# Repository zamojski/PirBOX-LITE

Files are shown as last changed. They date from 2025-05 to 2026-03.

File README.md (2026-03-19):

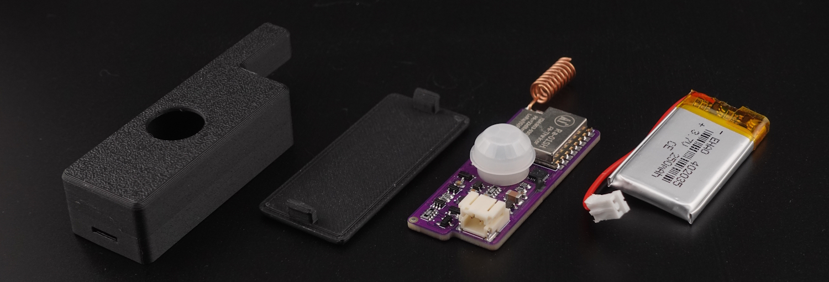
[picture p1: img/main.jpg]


🤗 Please consider subscribing to my [YouTube channel](https://www.youtube.com/@PricelessToolkit/videos)
Your subscription goes a long way in backing my work. If you feel more generous, you can buy me a coffee



## PirBOX-LITE and [PirBOX-MAX](https://github.com/PricelessToolkit/PirBOX-MAX)

**PirBOX-LITE** is an Open-Source, compact, low-power LoRa-based PIR motion sensor designed for long-range applications such as mailboxes, basements, underground "garages/parkings", and remote sheds. It is the improved, more affordable successor to the **[MailBox-Guard](https://github.com/PricelessToolkit/MailBoxGuard)** project.

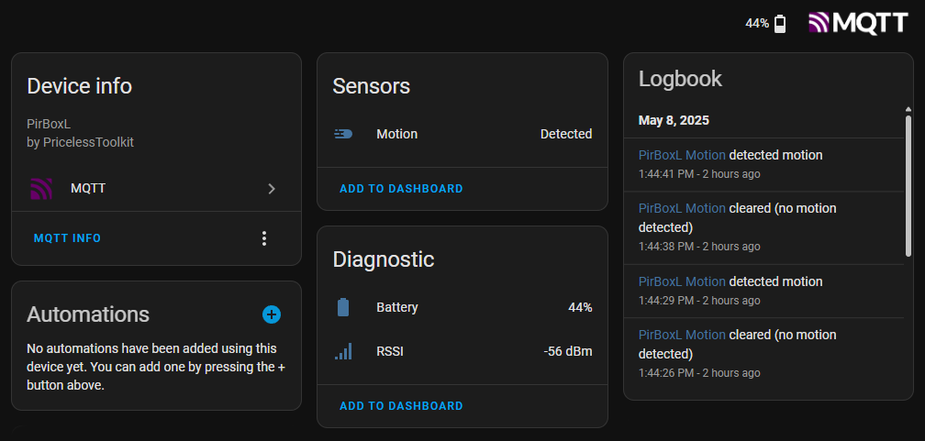
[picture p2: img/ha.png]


#### 🛒 Can be purchased in my shop http://www.PricelessToolkit.com

### ✨ Key Features:
- Seamless integration with **Home Assistant MQTT**  
- **LoRa-based communication** for long-range, low-power use cases  
- Sends **( Detected** / **Cleared )** statuses to a LoRa gateway "**[CapiBridge](https://github.com/PricelessToolkit/CapiBridge) or [LilyGo LoRa Board](https://github.com/PricelessToolkit/TTGO_Gateway)**"  
- **Ultra-low power consumption**: ~11 µAh when No motion detected
- Powered by a **250 mAh battery** for long-lasting operation
- Perfect for remote monitoring where Wi-Fi or Zigbee range isn't enough

> [!NOTE]
> **Not intended** for close proximity use or in high-traffic areas, Zigbee devices are better suited for those applications.

### 📋 Power Consumption Table
Measured by "Power Profiler KIT 2"

| Condition | Current Draw | Battery Life (approx.) |
|---|---|---|
| No motion detected | 11 µA | ~2.6 years (250 mAh / 11 µA) |
| Constant motion detected  | 25 µA | ~1.1 years (250 mAh / 25 µA) |
| Single status transmission (314 ms) | 4.02 µAh | ~62,188 sends (250,000 µAh / 4.02 µAh) |

> [!NOTE]
> Battery Life is only an approximate value. Actual battery life can vary depending on temperature, battery quality, configuration, and other factors.

### Required:
- [CapiBridge LoRa Gateway](https://github.com/PricelessToolkit/CapiBridge) has 2-Way communication and Encryption possibility, or the one-way more affordable version [TTGO_Gateway](https://github.com/PricelessToolkit/TTGO_Gateway) *no Encryption and future support is limited.
- Programmer [UNIProg](https://www.pricelesstoolkit.com/en/projects/33-uniprog-uartupdi-programmer-33v-0741049314412.html) or any other 3.3v UPDI Programmer
- LiPo Battery [1S 250mAh](https://www.pricelesstoolkit.com/en/products/47-battery-li-po-37v-250mah-ph-20mm-2-pin.html) or less (Connector PH2.0) Important! MAX SIZE "35x20x4mm"
- LiPo Charger [Micro-Charger](https://www.pricelesstoolkit.com/en/li-ion-li-poly/48-micro-charger-for-li-po-and-li-ion.html) or any other 4.2V lipo charger with (PH2.0)
- Pogo PIN Clamp 1x6 PIN "Only for convenience" https://s.click.aliexpress.com/e/_ooPke35

### Choosing a Gateway Hardware

1. [CapiBridge LoRa/ESP-NOW Gateway](https://github.com/PricelessToolkit/CapiBridge): I developed this project, featuring multi-protocol support, including LoRa and ESP-NOW. It supports 2-way communication with Encryption, making it possible to send commands to `LoRa` nodes as well as receive the sensor data. It will be compatible with my future LoRa and ESP-NOW sensor projects.
2. [LilyGo LoRa Board](https://github.com/PricelessToolkit/MailBoxGuard/tree/main?tab=readme-ov-file#select-ttgo_lora-board-version): This option is more affordable but only has LoRa and does not support Encryption.

### 📣 Updates, Bugfixes, and Breaking Changes
- 22.05.2025 - Breaking Change (XOR obfuscation "Encryption" for LoRa).
- - CapiBridge firmware needs to be updated.

### Configuration / Reflashing:
> [!NOTE]
> By default, it comes already flashed and tested with the default firmware, `GATEWAY_KEY "xy"` and `encryption_key { 0x4B, 0xA3, 0x3F, 0x9C }`. You need to change the keys!

1. Install MegaTinyCore in Arduino IDE "http://drazzy.com/package_drazzy.com_index.json"
2. Download the PirBOX-Lite project file; don't just copy and paste the code.
3. Open the PirBox-Lite.ino file in Arduino IDE. "It will include all necessary files and Radio Library."
4. In Config.h, change the sensor name, gateway key, and radio settings based on your gateway config

> [!IMPORTANT]  
> The PirBOX LoRa module uses the sync word `0x1424`, which is equivalent to the CapiBridge's `0x12` sync word.

```cpp
/////////////////////////// LoRa Gateway Key ///////////////////////////

#define GATEWAY_KEY "xy"                           // Separation Key "Keep it Short 2 letters is enough"
#define NODE_NAME "PirBoxL"                        // Sensor Name which will be visible in Home Assistant
#define Encryption true                            // Global Payload obfuscation (Encryption)
#define encryption_key_length 4                    // must match number of bytes in the XOR key array
#define encryption_key { 0x4B, 0xA3, 0x3F, 0x9C }  // Multi-byte XOR key (between 2–16 values).
                                                   // Use random-looking HEX values (from 0x00 to 0xFF).
                                                   // Must match exactly on both sender and receiver.
                                                   // Example: { 0x1F, 0x7E, 0xC2, 0x5A }  ➜ 4-byte key.

////////////////////////////// LORA CONFIG ////////////////////////////////////

#define BAND                      868E6     // 433E6 MHz or 868E6 MHz or 915E6 MHz
#define TX_OUTPUT_POWER           22       // dBm tx output power

//| Bandwidth | Supported Spreading Factors |
//|-----------|-----------------------------|
//| 125 kHz   | SF5 – SF9                   |
//| 250 kHz   | SF5 – SF10                  |
//| 500 kHz   | SF5 – SF11                  |

#define LORA_BANDWIDTH            5         // bandwidth 4: 125Khz, 5: 250KHZ, 6: 500Khz
#define LORA_SPREADING_FACTOR     10         // spreading factor 6-12 [SF5..SF11]
#define LORA_CODINGRATE           1         // [1: 4/5, 2: 4/6, 3: 4/7, 4: 4/8]
#define LORA_PREAMBLE_LENGTH      12         // Same for Tx and Rx
#define LORA_PAYLOADLENGTH        0         // 0: Variable length packet (explicit header),  1..255 for Fixed length packet (implicit header)
#define LORA_CRC_ON               true
#define LORA_SYNC_WORD            0x1424    // The 0x1424 private sync word is equivalent to the CapiBridge 0x12 sync word.

// LoRa Sync Word Compatibility Table
//
// This table shows how 16-bit sync words used on "PirBOX" SX126x-based modules (like Ra-01SH) correspond to the 8-bit sync words used on older SX127x-based modules.
//
// | Type    | SX126x Sync Word | SX127x Equivalent | Notes                                                               |
// |---------|------------------|-------------------|---------------------------------------------------------------------|
// | Public  | `0x3444`         | `0x34`            | Default for LoRaWAN. Reserved, do **not** use for private networks. |
// | Private | `0x1424`         | `0x12`            | Recommended for custom/private networks.                            |
// | Private | `0x1437`         | `0x37`            | Custom private network sync word.                                   |
// | Private | `0x14A9`         | `0xA9`            | Custom private network sync word.                                   |
// | Private | `0x14D5`         | `0xD5`            | Custom private network sync word.                                   |
//
// Notes:
// - SX126x uses a 16-bit sync word, always starting with `0x14` for compatibility.
// - SX127x uses an 8-bit sync word, derived from the lower byte (`0xYZ` from `0x14YZ`).
// - Avoid `0x3444` (`0x34`) in private networks — it's reserved for "LoRaWAN public" use.
// - Choose a unique `0x14YZ` value for a private network to avoid collisions and improve isolation.

```

5. Select board configuration as shown below.

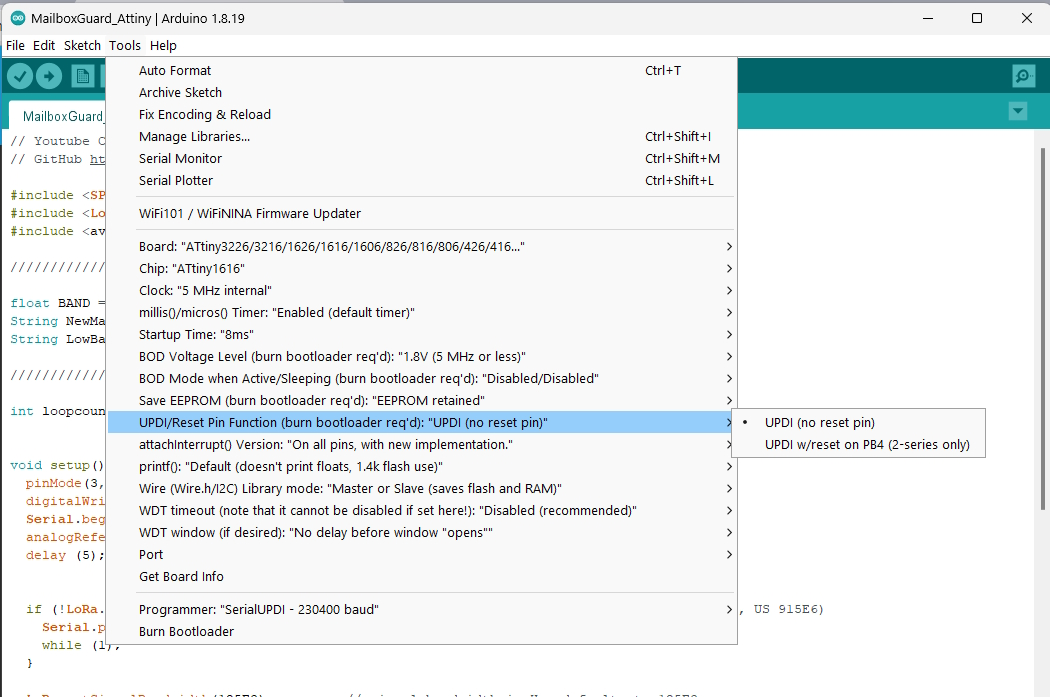
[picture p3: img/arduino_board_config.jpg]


6. Disconnect the Battery if connected. Then connect the UPDI programmer to the back of the PirBOX using the pogo pin clamp, or any method you prefer.

<table>
  <tr>
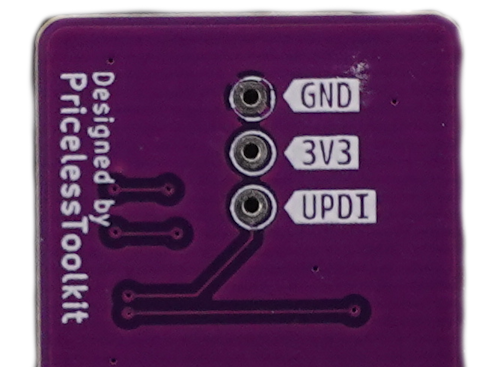
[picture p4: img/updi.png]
    <td></td>
    <td>

<!-- Markdown-style table inside HTML cell -->
  
| **PirBOX** | **Programmer** |
|---|---|
| 3.3V | 3.3V |
| GND | GND |
| UPDI | UPDI |

</table>

7. In Arduino IDE, select the COM Port and programmer "SerialUPDI-230400 baud "Required UPDI Programmer"
8. Click "Upload Using Programmer" or "Ctrl + Shift + U", Done!

If your gateway and sensor are configured correctly, you should see under MQTT Devices "PIRBoxL" or the custom name you assigned in the config.h file. Once it's visible under MQTT Devices, the next step is to create an automation in Home Assistant to send a notification to your mobile phone.

Below is an example automation that sends a message along with an image. This example is configured for a mailbox, but you can easily adapt it to fit your specific needs.

"Automation" Notification [Manual](https://companion.home-assistant.io/docs/notifications/actionable-notifications/)

```yaml

alias: Pirbox
description: "MailBoxSensor"
triggers:
  - type: motion
    device_id: 5e37501c1847ff9e185f293757ff91b3
    entity_id: 0cc089df300ab037a78abc906b9736af
    domain: binary_sensor
    trigger: device
conditions: []
actions:
  - data:
      message: Mailbox is Full!
      title: New Mail!
      data:
        url: /lovelace/home
        importance: high
        channel: MailBox
        tag: mailbox
        image: /media/local/notify/mailbox.jpg
    action: notify.mobile_app_doogee_v20pro

```
PS: mailbox.jpg is included in the "img" folder.

____________

# 🛠️ Prefer to build it on your own?
This project is open-source and includes Source code, 3D Print files, and Gerber files, allowing you to order blank PCBs and assemble the PirBOX-Lite yourself. To help with manual assembly, I've included an Interactive HTML BOM in the PCB folder. This tool shows the placement and polarity of each component, helping to eliminate errors during soldering.

> [!NOTE]
>  Please note that CPL file or POS "Pick and Place" files, and KiCad source files are not included. These are intentionally omitted, as this project is intended for manual assembly. If you prefer a ready-to-use solution, you can purchase one directly from my shop: https://www.pricelesstoolkit.com.

## Schematic
<details>
  <summary>View schematic. Click here</summary>
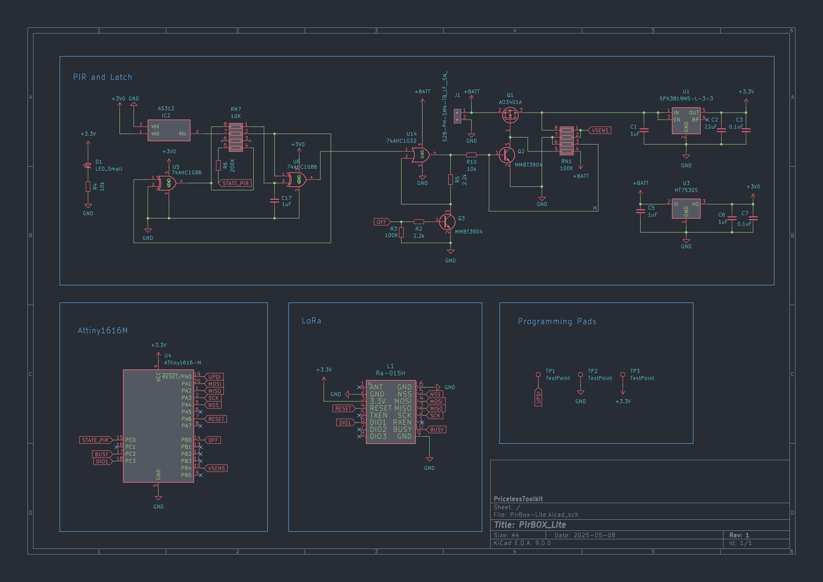
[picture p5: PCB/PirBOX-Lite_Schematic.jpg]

</details>

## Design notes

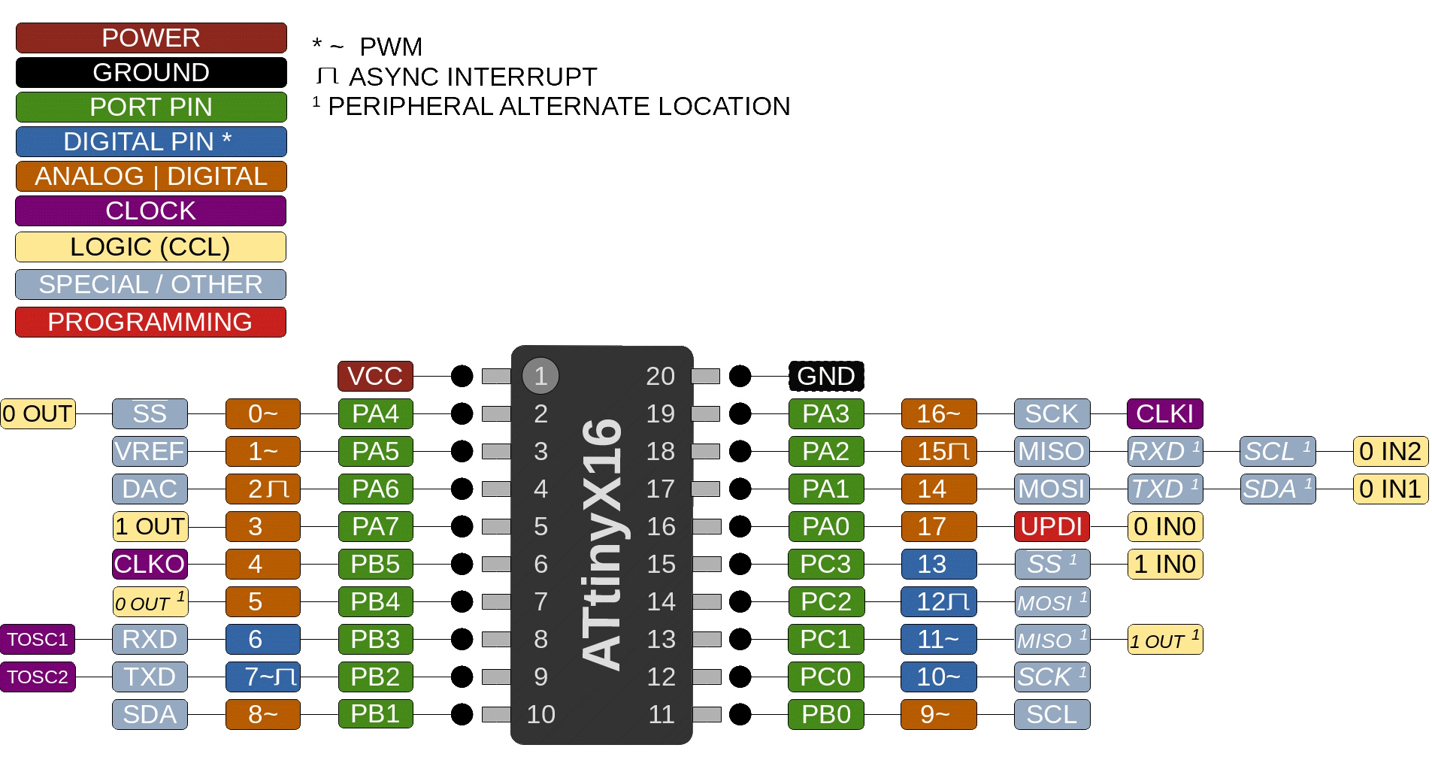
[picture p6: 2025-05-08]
img/ATtiny_x16.jpg

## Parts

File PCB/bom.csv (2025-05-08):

Designator | Footprint | Quantity | Value | LCSC Part #
C1, C17, C5, C6 | 0603 | 4 | 1uF
C2 | 1206 | 1 | 22uF
C3, C7 | 0603 | 2 | 0.1uF
D1 | 0603 | 1 | LED_Small
IC2 | AS312-NEW | 1 | AS312
J1 | JST_PH_S2B-PH-SM4-TB_1x02-1MP_P2.00mm_Horizontal | 1 | S2B-PH-SM4-TB_LF__SN_ | S2B-PH-SM4-TB(LF)(SN)
L1 | Ai-Thinker-Ra-01-LoRa | 1 | Ra-01SH
Q1 | SOT-23 | 1 | AO3401A
Q2, Q3 | SOT-23 | 2 | MMBT3904
R10, R4 | 0603 | 2 | 10k
R2, R5 | 0603 | 2 | 2.2k
R3 | 0603 | 1 | 100K
R6 | 0603 | 1 | 200K
RN1 | RESCAXE80P320X160X70-8N | 1 | 100K
RN7 | RESCAXE80P320X160X70-8N | 1 | 10K
TP1, TP2, TP3 | TestPoint_THTPad_D1.5mm_Drill0.7mm | 3 | TestPoint
U1 | SOT-23-5 | 1 | SPX3819M5-L-3-3
U14 | SOT-353_SC-70-5 | 1 | 74AHC1G32
U3 | SOT-23 | 1 | HT7530S
U4 | VQFN-20-1EP_3x3mm_P0.4mm_EP1.7x1.7mm | 1 | ATtiny1616-M
U5, U6 | SOT-353_SC-70-5 | 2 | 74AHC1G86

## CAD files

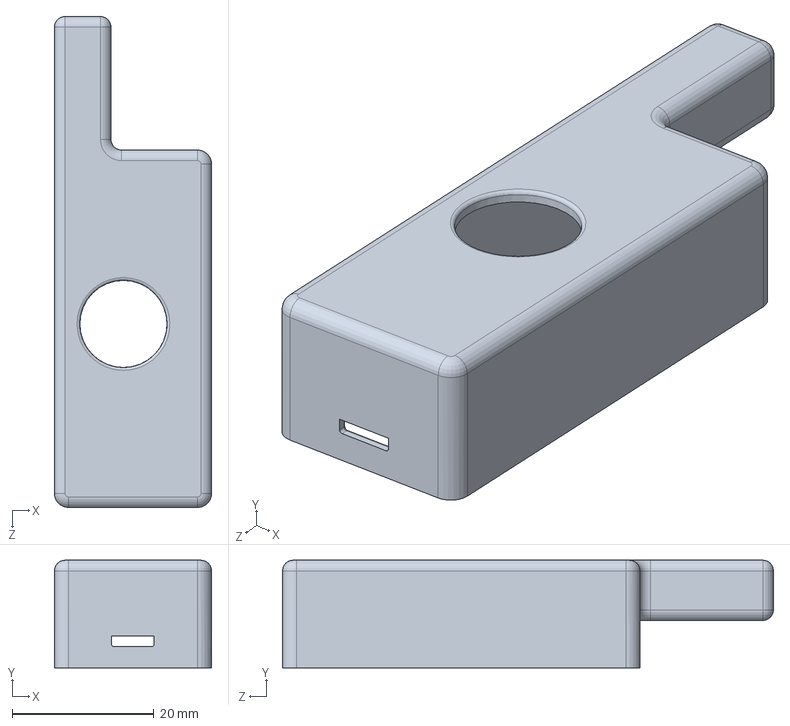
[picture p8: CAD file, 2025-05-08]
3D/Front.SLDPRT
22.2 x 15.2 x 69.4 mm

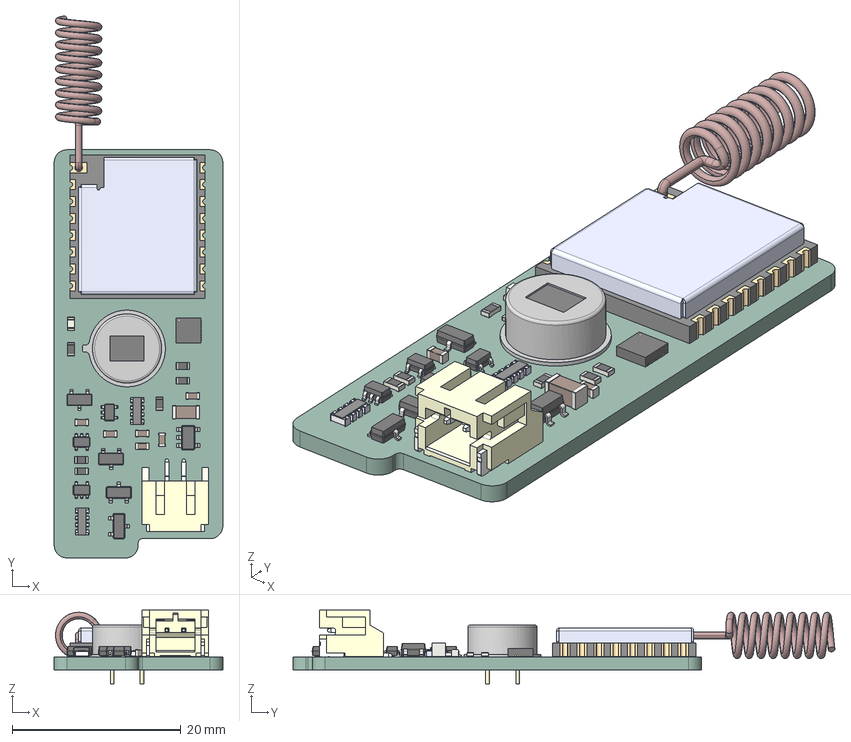
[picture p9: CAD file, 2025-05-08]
3D/PirBox_Mini.step
20.0 x 64.3 x 8.75 mm
C_0603_1608Metric x 6
SOT-23 x 4
R_0603_1608Metric x 6
SOT-23-5
LED_0603_1608Metric
AS312 AM312 PIR
SOT-353_SC-70-5 x 3
RA-01H--3DModel-STEP-1
SW868-TH13
C_1206_3216Metric
YC164-FR-075K6L x 2
DFN-20-1EP_5x6mm_P0.5mm_EP3.24x4.24mm
S2B-PH-SM4-TB(LF)(SN)--3DModel-STEP-56544
PirBox_Mini_PCB

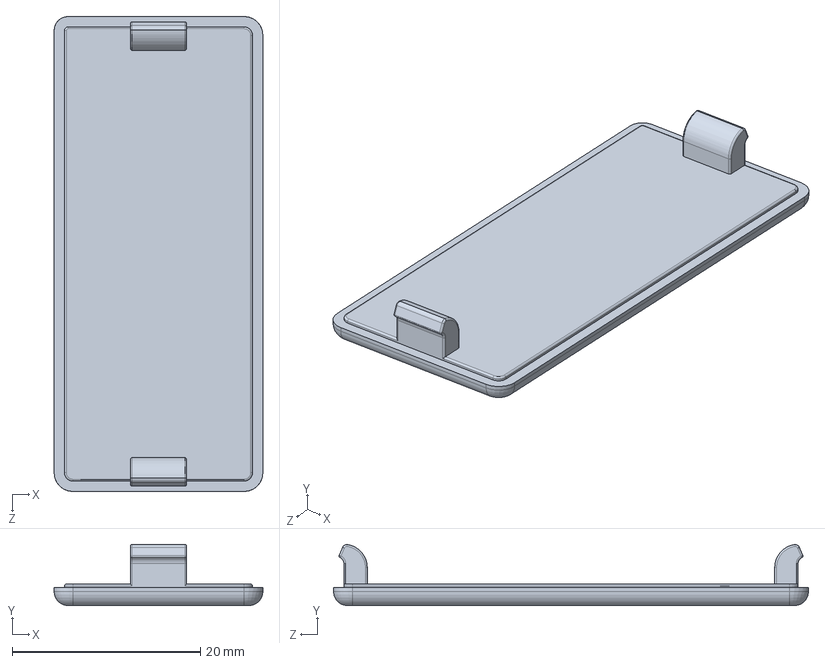
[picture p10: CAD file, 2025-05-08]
3D/Lid.SLDPRT
22.2 x 6.50 x 50.5 mm

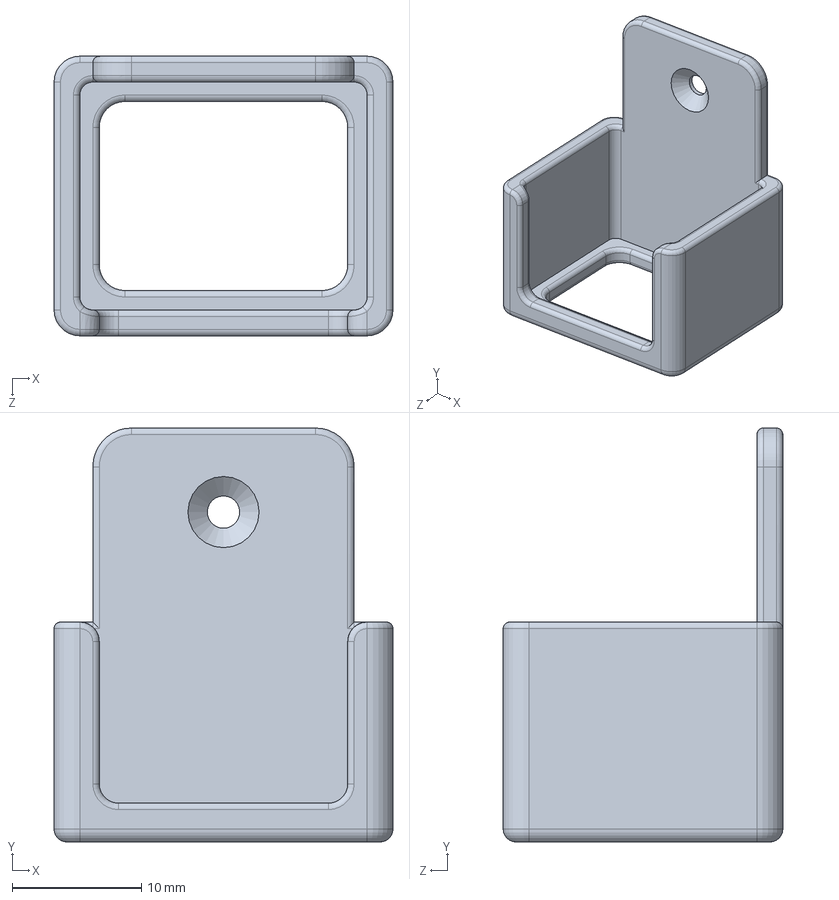
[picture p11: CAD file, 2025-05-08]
3D/Support.SLDPRT
26.2 x 32.0 x 21.6 mm

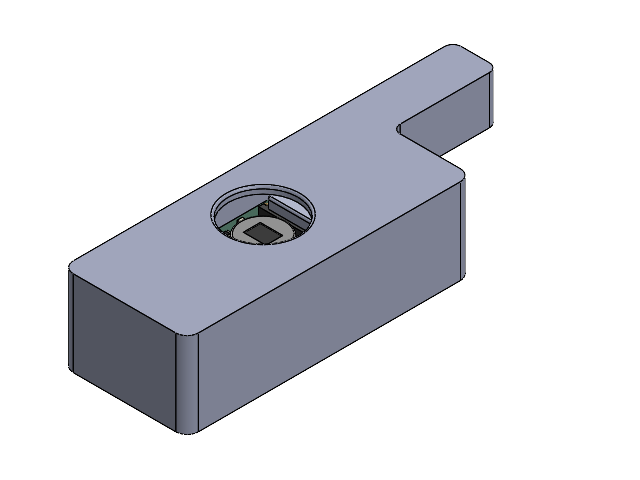
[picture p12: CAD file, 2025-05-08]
3D/Assem1.SLDASM
Part1_front
C_0603_1608Metric.step x 6
SOT-23.step x 4
R_0603_1608Metric.step x 6
SOT-23-5.step
LED_0603_1608Metric.step
AS312 AM312 PIR.step
SOT-353_SC-70-5.step x 3
RA-01H--3DModel-STEP-1.step
SW868-TH13.step
C_1206_3216Metric.step
YC164-FR-075K6L.step x 2
DFN-20-1EP_5x6mm_P0.5mm_EP3.24x4.24mm.step
S2B-PH-SM4-TB(LF)(SN)--3DModel-STEP-56544.step
PirBox_Mini_PCB.step

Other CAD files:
3D/Front.STL
3D/Lid.STL
3D/PirBox_Mini.SLDASM
3D/Support.STL

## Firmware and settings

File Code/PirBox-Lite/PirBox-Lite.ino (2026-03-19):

/***************************************************************
 * PirBox by PricelessToolkit — Interrupt-driven, binary-safe send
 * Requirements:
 *  - config.h (your version posted)
 *  - Ra01S / SX126x driver ("Ra01S.h")
 ***************************************************************/

#include "config.h"
#include <SPI.h>
#include "Ra01S.h"

// -------------------- PIN ASSIGNMENTS -------------------- //
#define PIR_PIN          PIN_PC0   // Motion sensor input
#define OFF_PIN          PIN_PB0   // Pull HIGH for Power OFF (latches power off)
#define BATT_PIN         PIN_PB4   // Battery sense pin

// RA-01SH / SX126x pins
#define RADIO_RESET_PIN  PIN_PA6
#define RADIO_NSS_PIN    PIN_PA4
#define RADIO_BUSY_PIN   PIN_PC2
#define RADIO_DIO1_PIN   PIN_PC3

SX126x lora(RADIO_NSS_PIN, RADIO_RESET_PIN, RADIO_BUSY_PIN);

// -------------------- STATE -------------------- //
volatile bool sensorTriggered = false;
volatile unsigned long lastInterruptTime = 0;   // for debounce
bool firstRun = true;

// -------------------- UTILS -------------------- //
/*
// XOR cipher using multi-byte key defined in config.h
static inline String xorCipher(const String& input) {
  const byte key[] = encryption_key;            // from config.h
  const int keyLength = encryption_key_length;  // from config.h

  String out;
  out.reserve(input.length());
  for (size_t i = 0; i < (size_t)input.length(); ++i) {
    byte keyByte = key[i % keyLength];
    out += char(uint8_t(input[i]) ^ keyByte);
  }
  return out;
}

*/


// -------------------- XOR+BAS64----------------------//

// config.h has:
// #define encryption_key_length 4
// #define encryption_key { 0x4B, 0xA3, 0x3F, 0x9C }

String xorCipher(String in) {
  // 1) Use an ARRAY, not a pointer, for the macro initializer
  static const uint8_t key[] = encryption_key;
  const int K = encryption_key_length;

  auto isB64 = [](const String& s)->bool{
    if (s.length() % 4) return false;
    for (size_t i=0;i<s.length();++i){
      char c=s[i];
      if (!((c>='A'&&c<='Z')||(c>='a'&&c<='z')||(c>='0'&&c<='9')||c=='+'||c=='/'||c=='=')) return false;
    }
    return true;
  };

  auto b64enc = [](const uint8_t* b, size_t n)->String{
    static const char T[]="ABCDEFGHIJKLMNOPQRSTUVWXYZabcdefghijklmnopqrstuvwxyz0123456789+/";
    String o; o.reserve(((n+2)/3)*4);
    for(size_t i=0;i<n;i+=3){
      uint32_t v = ((uint32_t)b[i] << 16)
                 | ((i+1<n ? (uint32_t)b[i+1] : 0) << 8)
                 |  (i+2<n ? (uint32_t)b[i+2] : 0);
      o += T[(v>>18)&63]; o += T[(v>>12)&63];
      o += (i+1<n) ? T[(v>>6)&63] : '=';
      o += (i+2<n) ? T[v&63]      : '=';
    }
    return o;
  };

  auto b64val = [](char c)->int{
    if(c>='A'&&c<='Z') return c-'A';
    if(c>='a'&&c<='z') return 26+c-'a';
    if(c>='0'&&c<='9') return 52+c-'0';
    if(c=='+') return 62;
    if(c=='/') return 63;
    return -1;
  };

  auto b64dec = [&](const String& s)->String{
    String o; o.reserve((s.length()/4)*3);
    for(size_t i=0;i<s.length(); i+=4){
      int a=b64val(s[i]), b=b64val(s[i+1]);
      int c = (s[i+2]=='=') ? -1 : b64val(s[i+2]);
      int d = (s[i+3]=='=') ? -1 : b64val(s[i+3]);

      // 2) Upcast before shifting (AVR int is 16-bit)
      uint32_t v = ((uint32_t)(a & 63) << 18)
                 | ((uint32_t)(b & 63) << 12)
                 | ((uint32_t)((c < 0 ? 0 : (c & 63))) << 6)
                 |  (uint32_t)((d < 0 ? 0 : (d & 63)));

      o += (char)((v >> 16) & 0xFF);
      if (c >= 0) o += (char)((v >> 8) & 0xFF);
      if (d >= 0) o += (char)(v & 0xFF);
    }
    return o;
  };

  if (isB64(in)) {                 // decrypt: Base64 -> XOR -> JSON
    String bytes = b64dec(in);
    String out; out.reserve(bytes.length());
    for (size_t i=0;i<bytes.length();++i)
      out += (char)(((uint8_t)bytes[i]) ^ key[i % K]);
    return out;
  } else {                         // encrypt: JSON -> XOR -> Base64
    String x; x.reserve(in.length());
    for (size_t i=0;i<in.length();++i)
      x += (char)(((uint8_t)in[i]) ^ key[i % K]);
    return b64enc((const uint8_t*)x.c_str(), x.length());
  }
}


//------------------ XOR END -------------------------------//







// Power latch off (your hardware should cut power after this line)
static inline void powerOFF() {
  delay(100);
  digitalWrite(OFF_PIN, HIGH); // Powering off
}

// Battery level (0–100%), using 2.5V ref and divider = x2
static inline int batt() {
  float totalVolts = 0.0f;
  for (int i = 0; i < 5; i++) {
    float volts = analogReadEnh(BATT_PIN, 12) * (2.5f / 4096.0f) * 2.0f;
    totalVolts += volts;
    delay(2);
  }
  float averageVolts = totalVolts / 5.0f;

  // Map ~3.3V..4.1V to 0..100%
  float percentage = ((averageVolts - 3.3f) / (4.1f - 3.3f)) * 100.0f;
  if (percentage < 0)   percentage = 0;
  if (percentage > 100) percentage = 100;
  return (int)(percentage + 0.5f);
}

// -------------------- RADIO -------------------- //
static inline void initLoRaRadio() {
  int16_t ret = lora.begin(BAND, TX_OUTPUT_POWER);
  if (ret != ERR_NONE) {
    // Halt if init fails
    while (1) { }
  }

  // If you want to set a custom SX126x sync word manually, you can:
  // lora.SetSyncWord(LORA_SYNC_WORD);

  lora.LoRaConfig(
    LORA_SPREADING_FACTOR,
    LORA_BANDWIDTH,
    LORA_CODINGRATE,
    LORA_PREAMBLE_LENGTH,
    LORA_PAYLOADLENGTH,   // 0 => explicit header (variable length)
    LORA_CRC_ON,
    false,                // IQ inversion
    LORA_SYNC_WORD        // must match CapiBridge's effective sync (0x1424 -> 0x12)
  );
}

// -------------------- ISR -------------------- //
void sensorISR() {
  unsigned long now = millis();
  // Debounce (~80 ms to tame PIR chatter on wake)
  if (now - lastInterruptTime > 80) {
    sensorTriggered = true;
    lastInterruptTime = now;
  }
}

// -------------------- ARDUINO -------------------- //
void setup() {
  pinMode(OFF_PIN, OUTPUT);
  digitalWrite(OFF_PIN, LOW);      // keep device powered

  pinMode(PIR_PIN, INPUT);
  pinMode(RADIO_DIO1_PIN, INPUT);

  // Optional serial for debug (avoid printing encrypted payloads!)
  // Serial.begin(9600);

  initLoRaRadio();

  // Use 2.5V internal reference for stable battery measurement
  analogReference(INTERNAL2V5);

  // Interrupt on rising edge only (ON events)
  attachInterrupt(digitalPinToInterrupt(PIR_PIN), sensorISR, RISING);
}

void loop() {
  // Trigger on first boot or when PIR goes HIGH
  if (sensorTriggered || firstRun) {
    sensorTriggered = false;
    if (firstRun) firstRun = false;

    // Read PIR state (true = motion)
    const bool pirOn = (digitalRead(PIR_PIN) == HIGH);

    // Build compact JSON
    String payload;
    payload.reserve(64);
    payload  = "{\"k\":\""; payload += GATEWAY_KEY;
    payload += "\",\"id\":\""; payload += NODE_NAME; payload += "\"";
    payload += ",\"m\":\""; payload += (pirOn ? "on" : "off"); payload += "\"";
    payload += ",\"b\":"; payload += batt();
    payload += "}";

    // Copy to TX buffer (binary-safe)
    uint8_t buf[255];
    size_t len = payload.length();
    if (len > sizeof(buf)) len = sizeof(buf);   // clamp to buffer size
    memcpy(buf, payload.c_str(), len);          // copy plaintext

    // Apply XOR obfuscation (manual loop)
    #if Encryption
      static const uint8_t key[] = encryption_key;
      const int K = encryption_key_length;
      for (size_t i = 0; i < len; ++i) {
        buf[i] ^= key[i % K];
      }
    #endif

    // Send over LoRa
    if (lora.Send(buf, len, SX126x_TXMODE_SYNC)) {
      // Success — do not print encrypted data
      delay(20);
    } else {
      // Optional retry/backoff
      // delay(30);
      // lora.Send(buf, len, SX126x_TXMODE_SYNC);
    }

    // Cut power (hardware should latch off)
    powerOFF();
  }

  // Idle; device likely powers off after send
}

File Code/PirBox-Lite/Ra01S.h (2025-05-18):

#ifndef _RA01S_H
#define _RA01S_H

//return values
#define ERR_NONE                        0
#define ERR_PACKET_TOO_LONG             1
#define ERR_UNKNOWN                     2
#define ERR_TX_TIMEOUT                  3
#define ERR_RX_TIMEOUT                  4
#define ERR_CRC_MISMATCH                5
#define ERR_WRONG_MODEM                 6
#define ERR_INVALID_BANDWIDTH           7
#define ERR_INVALID_SPREADING_FACTOR    8
#define ERR_INVALID_CODING_RATE         9
#define ERR_INVALID_FREQUENCY_DEVIATION 10
#define ERR_INVALID_BIT_RATE            11
#define ERR_INVALID_RX_BANDWIDTH        12
#define ERR_INVALID_DATA_SHAPING        13
#define ERR_INVALID_SYNC_WORD           14
#define ERR_INVALID_OUTPUT_POWER        15
#define ERR_INVALID_MODE                16
#define ERR_INVALID_TRANCEIVER          17

// SX126X physical layer properties
#define XTAL_FREQ                       ( double )32000000
#define FREQ_DIV                        ( double )pow( 2.0, 25.0 )
#define FREQ_STEP                       ( double )( XTAL_FREQ / FREQ_DIV )
#define BUSY_WAIT                       5000

// SX126X Model
#define SX1261_TRANCEIVER                             0x01
#define SX1262_TRANCEIVER                             0x02
#define SX1268_TRANCEIVER                             0x08

// SX126X SPI commands
// operational modes commands
#define SX126X_CMD_NOP                                0x00
#define SX126X_CMD_SET_SLEEP                          0x84
#define SX126X_CMD_SET_STANDBY                        0x80
#define SX126X_CMD_SET_FS                             0xC1
#define SX126X_CMD_SET_TX                             0x83
#define SX126X_CMD_SET_RX                             0x82
#define SX126X_CMD_STOP_TIMER_ON_PREAMBLE             0x9F
#define SX126X_CMD_SET_RX_DUTY_CYCLE                  0x94
#define SX126X_CMD_SET_CAD                            0xC5
#define SX126X_CMD_SET_TX_CONTINUOUS_WAVE             0xD1
#define SX126X_CMD_SET_TX_INFINITE_PREAMBLE           0xD2
#define SX126X_CMD_SET_REGULATOR_MODE                 0x96
#define SX126X_CMD_CALIBRATE                          0x89
#define SX126X_CMD_CALIBRATE_IMAGE                    0x98
#define SX126X_CMD_SET_PA_CONFIG                      0x95
#define SX126X_CMD_SET_RX_TX_FALLBACK_MODE            0x93

// register and buffer access commands
#define SX126X_CMD_WRITE_REGISTER                     0x0D
#define SX126X_CMD_READ_REGISTER                      0x1D
#define SX126X_CMD_WRITE_BUFFER                       0x0E
#define SX126X_CMD_READ_BUFFER                        0x1E

// DIO and IRQ control
#define SX126X_CMD_SET_DIO_IRQ_PARAMS                 0x08
#define SX126X_CMD_GET_IRQ_STATUS                     0x12
#define SX126X_CMD_CLEAR_IRQ_STATUS                   0x02
#define SX126X_CMD_SET_DIO2_AS_RF_SWITCH_CTRL         0x9D
#define SX126X_CMD_SET_DIO3_AS_TCXO_CTRL              0x97

// RF, modulation and packet commands
#define SX126X_CMD_SET_RF_FREQUENCY                   0x86
#define SX126X_CMD_SET_PACKET_TYPE                    0x8A
#define SX126X_CMD_GET_PACKET_TYPE                    0x11
#define SX126X_CMD_SET_TX_PARAMS                      0x8E
#define SX126X_CMD_SET_MODULATION_PARAMS              0x8B
#define SX126X_CMD_SET_PACKET_PARAMS                  0x8C
#define SX126X_CMD_SET_CAD_PARAMS                     0x88
#define SX126X_CMD_SET_BUFFER_BASE_ADDRESS            0x8F
#define SX126X_CMD_SET_LORA_SYMB_NUM_TIMEOUT          0xA0

#define SX126X_PA_CONFIG_SX1261                       0x01
#define SX126X_PA_CONFIG_SX1262                       0x00

// status commands
#define SX126X_CMD_GET_STATUS                         0xC0
#define SX126X_CMD_GET_RSSI_INST                      0x15
#define SX126X_CMD_GET_RX_BUFFER_STATUS               0x13
#define SX126X_CMD_GET_PACKET_STATUS                  0x14
#define SX126X_CMD_GET_DEVICE_ERRORS                  0x17
#define SX126X_CMD_CLEAR_DEVICE_ERRORS                0x07
#define SX126X_CMD_GET_STATS                          0x10
#define SX126X_CMD_RESET_STATS                        0x00


// SX126X register map
#define SX126X_REG_HOPPING_ENABLE                     0x0385
#define SX126X_REG_PACKECT_LENGTH                     0x0386
#define SX126X_REG_NB_HOPPING_BLOCKS                  0x0387
#define SX126X_REG_NB_SYMBOLS0                        0x0388
#define SX126X_REG_FREQ0                              0x038A
#define SX126X_REG_NB_SYMBOLS15                       0x03E2
#define SX126X_REG_FREQ15                             0x03E4
#define SX126X_REG_DIOX_OUTPUT_ENABLE                 0x0580
#define SX126X_REG_DIOX_INPUT_ENABLE                  0x0583
#define SX126X_REG_DIOX_PILL_UP_CONTROL               0x0584
#define SX126X_REG_DIOX_PULL_DOWN_CONTROL             0x0585
#define SX126X_REG_WHITENING_INITIAL_MSB              0x06B8
#define SX126X_REG_WHITENING_INITIAL_LSB              0x06B9
#define SX126X_REG_CRC_INITIAL_MSB                    0x06BC
#define SX126X_REG_CRC_INITIAL_LSB                    0x06BD
#define SX126X_REG_CRC_POLYNOMIAL_MSB                 0x06BE
#define SX126X_REG_CRC_POLYNOMIAL_LSB                 0x06BF
#define SX126X_REG_SYNC_WORD_0                        0x06C0
#define SX126X_REG_SYNC_WORD_1                        0x06C1
#define SX126X_REG_SYNC_WORD_2                        0x06C2
#define SX126X_REG_SYNC_WORD_3                        0x06C3
#define SX126X_REG_SYNC_WORD_4                        0x06C4
#define SX126X_REG_SYNC_WORD_5                        0x06C5
#define SX126X_REG_SYNC_WORD_6                        0x06C6
#define SX126X_REG_SYNC_WORD_7                        0x06C7
#define SX126X_REG_NODE_ADDRESS                       0x06CD
#define SX126X_REG_BROADCAST_ADDRESS                  0x06CE
#define SX126X_REG_IQ_POLARITY_SETUP                  0x0736
#define SX126X_REG_LORA_SYNC_WORD_MSB                 0x0740
#define SX126X_REG_LORA_SYNC_WORD_LSB                 0x0741
#define SX126X_REG_RANDOM_NUMBER_0                    0x0819
#define SX126X_REG_RANDOM_NUMBER_1                    0x081A
#define SX126X_REG_RANDOM_NUMBER_2                    0x081B
#define SX126X_REG_RANDOM_NUMBER_3                    0x081C
#define SX126X_REG_TX_MODULETION                      0x0889
#define SX126X_REG_RX_GAIN                            0x08AC
#define SX126X_REG_TX_CLAMP_CONFIG                    0x08D8
#define SX126X_REG_OCP_CONFIGURATION                  0x08E7
#define SX126X_REG_RTC_CONTROL                        0x0902
#define SX126X_REG_XTA_TRIM                           0x0911
#define SX126X_REG_XTB_TRIM                           0x0912
#define SX126X_REG_DIO3_OUTPUT_VOLTAGE_CONTROL        0x0920
#define SX126X_REG_EVENT_MASK                         0x0944
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
